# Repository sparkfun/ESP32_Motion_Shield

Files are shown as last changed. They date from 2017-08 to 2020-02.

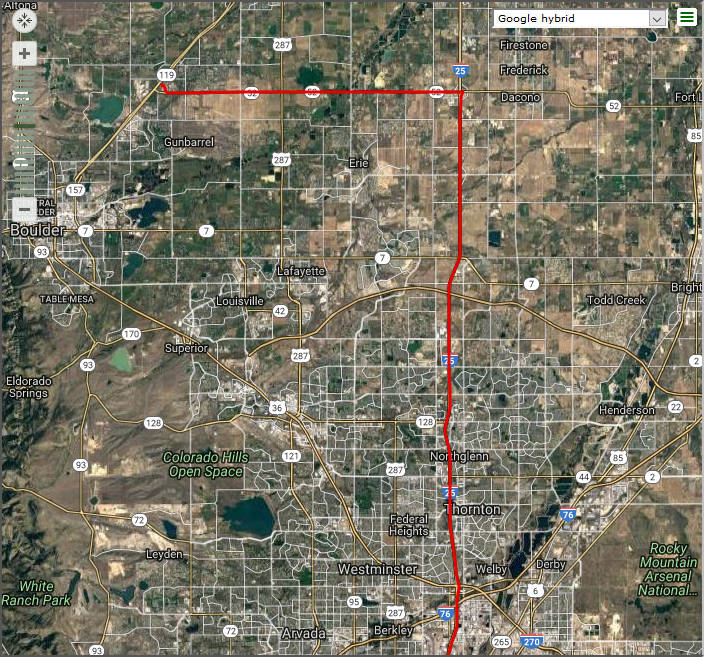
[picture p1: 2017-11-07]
Software/GPS_IMU_SD_Logger/extras/data_track.jpg

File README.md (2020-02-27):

SparkFun <PRODUCT NAME>
========================================

ESP32 Thing Motion Shield

The [ESP32 Thing Motion Shield](https://www.sparkfun.com/products/14430) is a versatile addition to our [ESP32 Thing](https://www.sparkfun.com/products/13907).  Small movements can be detected with the tried and true LSM9DS1 IMU, large movements and time can be detected with the addition of a GPS sensor.  There's a port for the [GP-20U7](https://www.sparkfun.com/products/13740) module, and breakout pins for any serial device.  Data can be easily logged by adding an microSD card to the slot.  There is also an additional user led on pin 13.

Repository Contents
-------------------

* **/Documentation** - Test plan and record.
* **/Hardware** - Eagle design files (.brd, .sch)
* **/Production** - Production panel files (.brd)
* **/Software** - Example programs for the ESP32 that can support functions of the Motion Shield.  These are used in the hookup guide.

Documentation
--------------
* **[Motion Shield Hookup Guide](https://learn.sparkfun.com/tutorials/esp32-thing-motion-shield-hookup-guide)** - Basic hookup guide for the ESP32 Motion Shield.
* **[ESP32 Hookup Guide](https://learn.sparkfun.com/tutorials/esp32-thing-hookup-guide)** - Basic hookup guide for the ESP32 Thing.

Product Versions
----------------
* [DEV-14430](https://www.sparkfun.com/products/14430) - ESP32 Motion Shield

Version History
---------------
* [V_1.0.0a](https://github.com/sparkfun/ESP32_Motion_Shield/releases/tag/v1.0.0a) - Software Update.
* [V_1.0.0](https://github.com/sparkfun/ESP32_Motion_Shield/tree/V_1.0.0) - Product release.

License Information
-------------------

This product is _**open source**_! 

Please review the LICENSE.md file for license information. 

If you have any questions or concerns on licensing, please contact techsupport@sparkfun.com.

Distributed as-is; no warranty is given.

- Your friends at SparkFun.

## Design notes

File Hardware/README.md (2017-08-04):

SparkFun <PRODUCT NAME> Design Files
=====================================

The .sch and .brd files hare are Eagle CAD schematic and PCB design files from SparkFun Electronics.
A freeware version of Eagle can be found [here](http://www.cadsoftusa.com/download-eagle/freeware/).

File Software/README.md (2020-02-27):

SparkFun ESP32 Motion Shield Software
=================================

Example software for use with SparkFun ESP32 Motion Shield.

LSM9DS1 and BME280 libraries need to be installed to work.

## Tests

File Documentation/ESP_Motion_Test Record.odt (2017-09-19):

# Functional Test Record

## SD card SPI bus and signal integrity

Configure an SD card to operate at fastest speed possible.

Procedure:

1. Perform 1M R/W test,
  1. Measure and record bus speed: __________
  2. Capture and record transaction beginning end such that timing can be seen, record two captures here

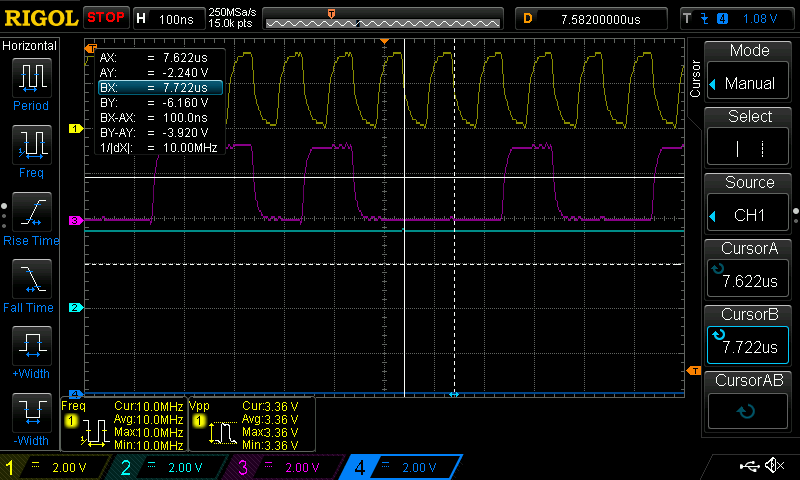
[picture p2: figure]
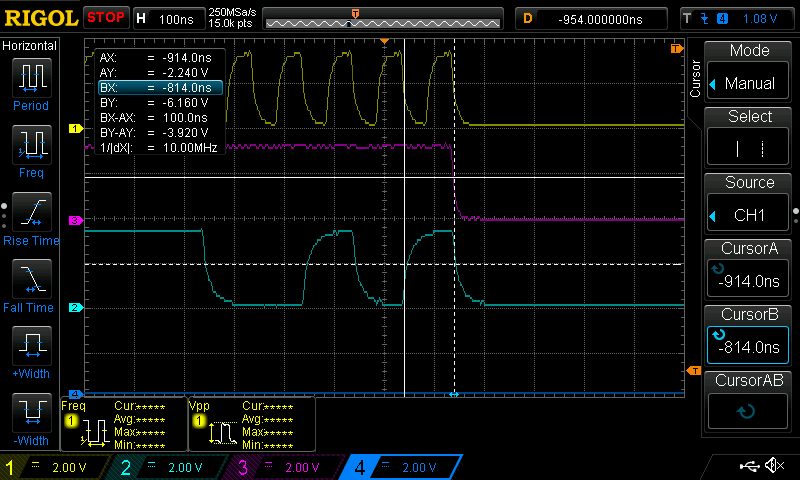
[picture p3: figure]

  1. Load the bus with another device
  2. Capture and record transaction beginning end such that timing can be seen, record two captures here

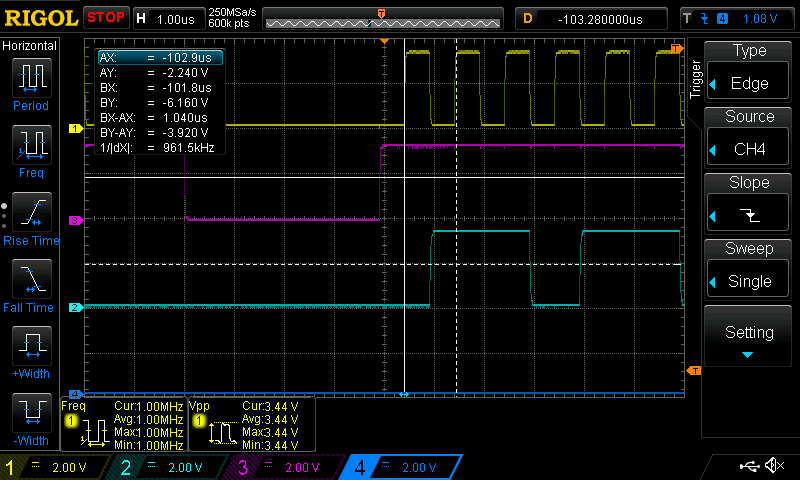
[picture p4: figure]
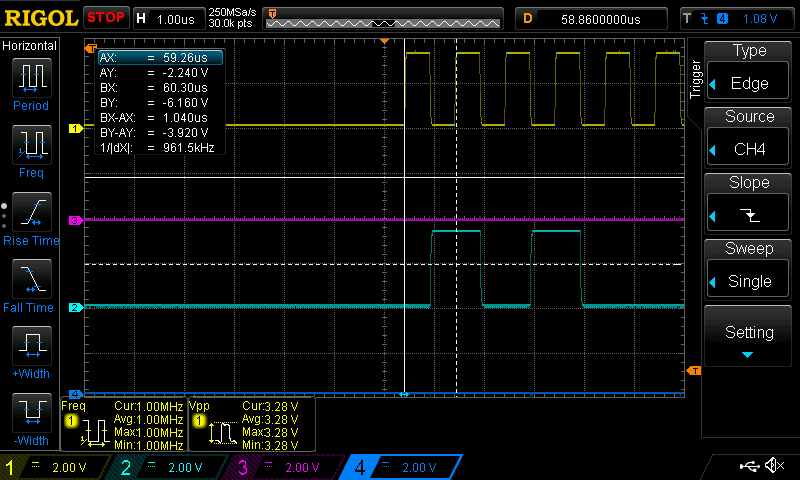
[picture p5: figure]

Criteria:

1. Does the SD car work alone, and with multiple devices? YES, Same bus speed limitation (probably max 1MHz)
2. Does the other device also work? YES
3. Do signals have sufficient setup and hold times? YES
4. Are signals monotonic? YES

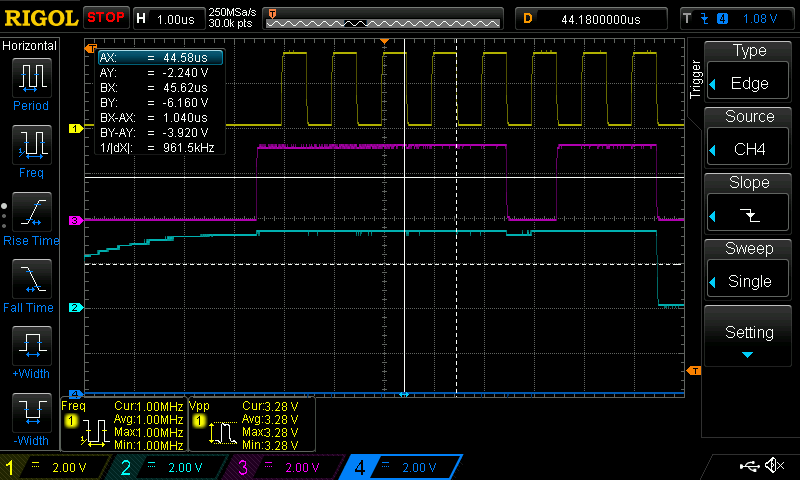
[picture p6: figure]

5. Are signals monotonic? YES/NO

## Check SD card CD function

Configure for SD card detection

Procedure:

1. With no card inserted, measure voltage on detect pin_____
2. With card inserted, measure voltage on detect pin_____
3. Recored pin configuration necessary here:

Criteria:

1. Do voltages fall outside ESP32 IO levels? NO – CD incorrectly wired, fixing in next rev

## IMU

Configure the gyro and accelerometer for use and measure bus conditions. Make a program that continuously reads all 9 axes.

Peform the following during read loop:

Procedure:

1. Measure and record bus speed: 100KHz
2. Capture and record transaction beginning end such that timing can be seen, record two captures here

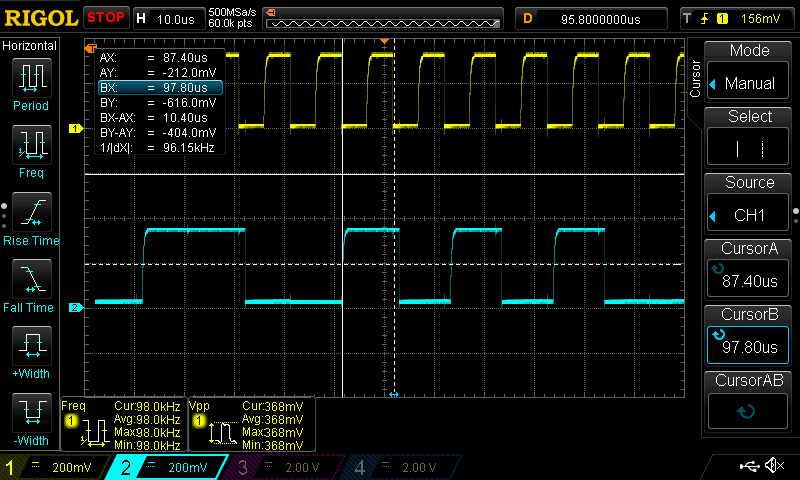
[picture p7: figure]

3. Load the bus with another device
4. Capture and record transaction beginning end such that timing can be seen, record two captures here

Criteria:

1. Does the other device also work? YES
2. Do signals have sufficient setup and hold times? YES
3. Are signals monotonic? YES

## Test IMU power features

Power switch has been scrapped

## Test the GPS port

Check that the serial pass-through is working fine

Procedure:

1. Loop-back the serial port
2. Run a program to return usb serial commands through the port
3. Capture a bit-variable character up to 115200 baud, measuring on the loopback
4. Measure the symbol rate for 9600, 57600, and 115200
  1. 9600: 9709, coming from cheap GPS, 9652 from loopback
  2. 57600: 57800 from loopback
  3. 115200: 115200 from loopback

Criteria:

1. Do the symbols have good integrity up to 115200? YES
2. Is the symbol rate correct? YES

## Test GPS module functionality

Expose GPS modules to the sky and check features

Procedure:

1. Attach 3 pin module.
2. Power device and wait for lock, record: _____
3. Record sample output:
4. Attach 4 pin module to holes
5. Power device and wait for lock, record: _____
6. Record sample output:

Criteria:

1. Does the cheap module work well? YES
2. Does the expensive module work well? SKIPPED
3. Is one module better than the other? YES/NO

## Test board power rails

Check that nothing is behaving stragely

For these tests, all functions should be running at greatest load

Procedure:

1. Measure ripple on power supply lines of shield: 7.6 mV p-p
2. Attach current probe to isolate 3.3V rail
3. Measure full load power draw: _____
4. Switch board on and off
5. Measure 3.3V rail rise time: 70uS

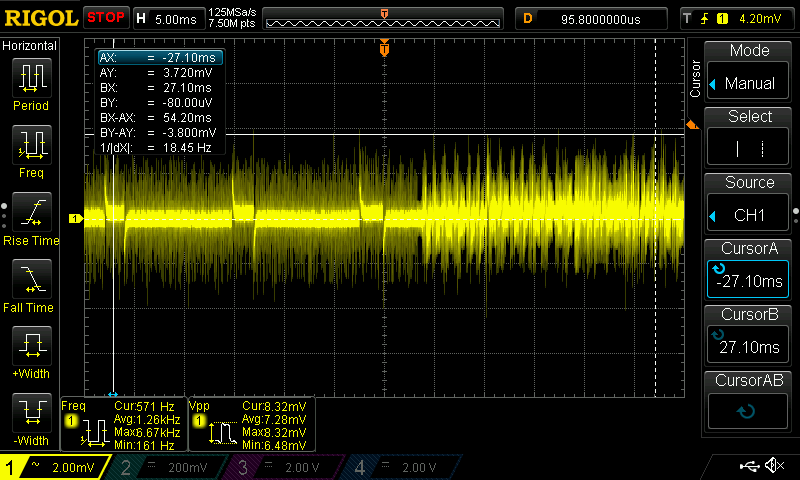
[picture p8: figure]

Criteria:

1. Is the current draw acceptable for battery use? SKIPPED
2. Is the rise time ok, > 10uS for IMU? YES
3. Is the ripple acceptable? YES

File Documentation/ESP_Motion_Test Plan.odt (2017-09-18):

# Functional Test Plan

## Features to verify

- SD card
  - Compatibility with other devices
  - Does CD work?
  - Signal integrity
- IMU
  - Gyro config and data
  - Accel config and data
  - Are additional pins needed?
  - Does power reset function? (can it be cold reboot?)
  - Signal integrity
- GPS
  - Does recommended GPS do its job?
  - Does hand-wired GPS also work?
  - Signal integrity
- Generic
  - What is the current consumption?
  - Are rise times OK?
  - Noise on power and ground?

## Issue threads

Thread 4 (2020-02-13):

Sensor fusion

romatou18, 2020-02-13:
hi I just had a quick look at the calcAttidude() function, if im correct it does not use any advanced, and now mainstream sensor fusion algorithm such as the Madgwick, or Mahony quarternion method ?

Do you plan on providing an algo for this board, this sensor ? The project has been out since 2017 it is kind of expected to have a decent IMU fusion integrated in the provided software perhaps.

Could you let us know ?

REgards

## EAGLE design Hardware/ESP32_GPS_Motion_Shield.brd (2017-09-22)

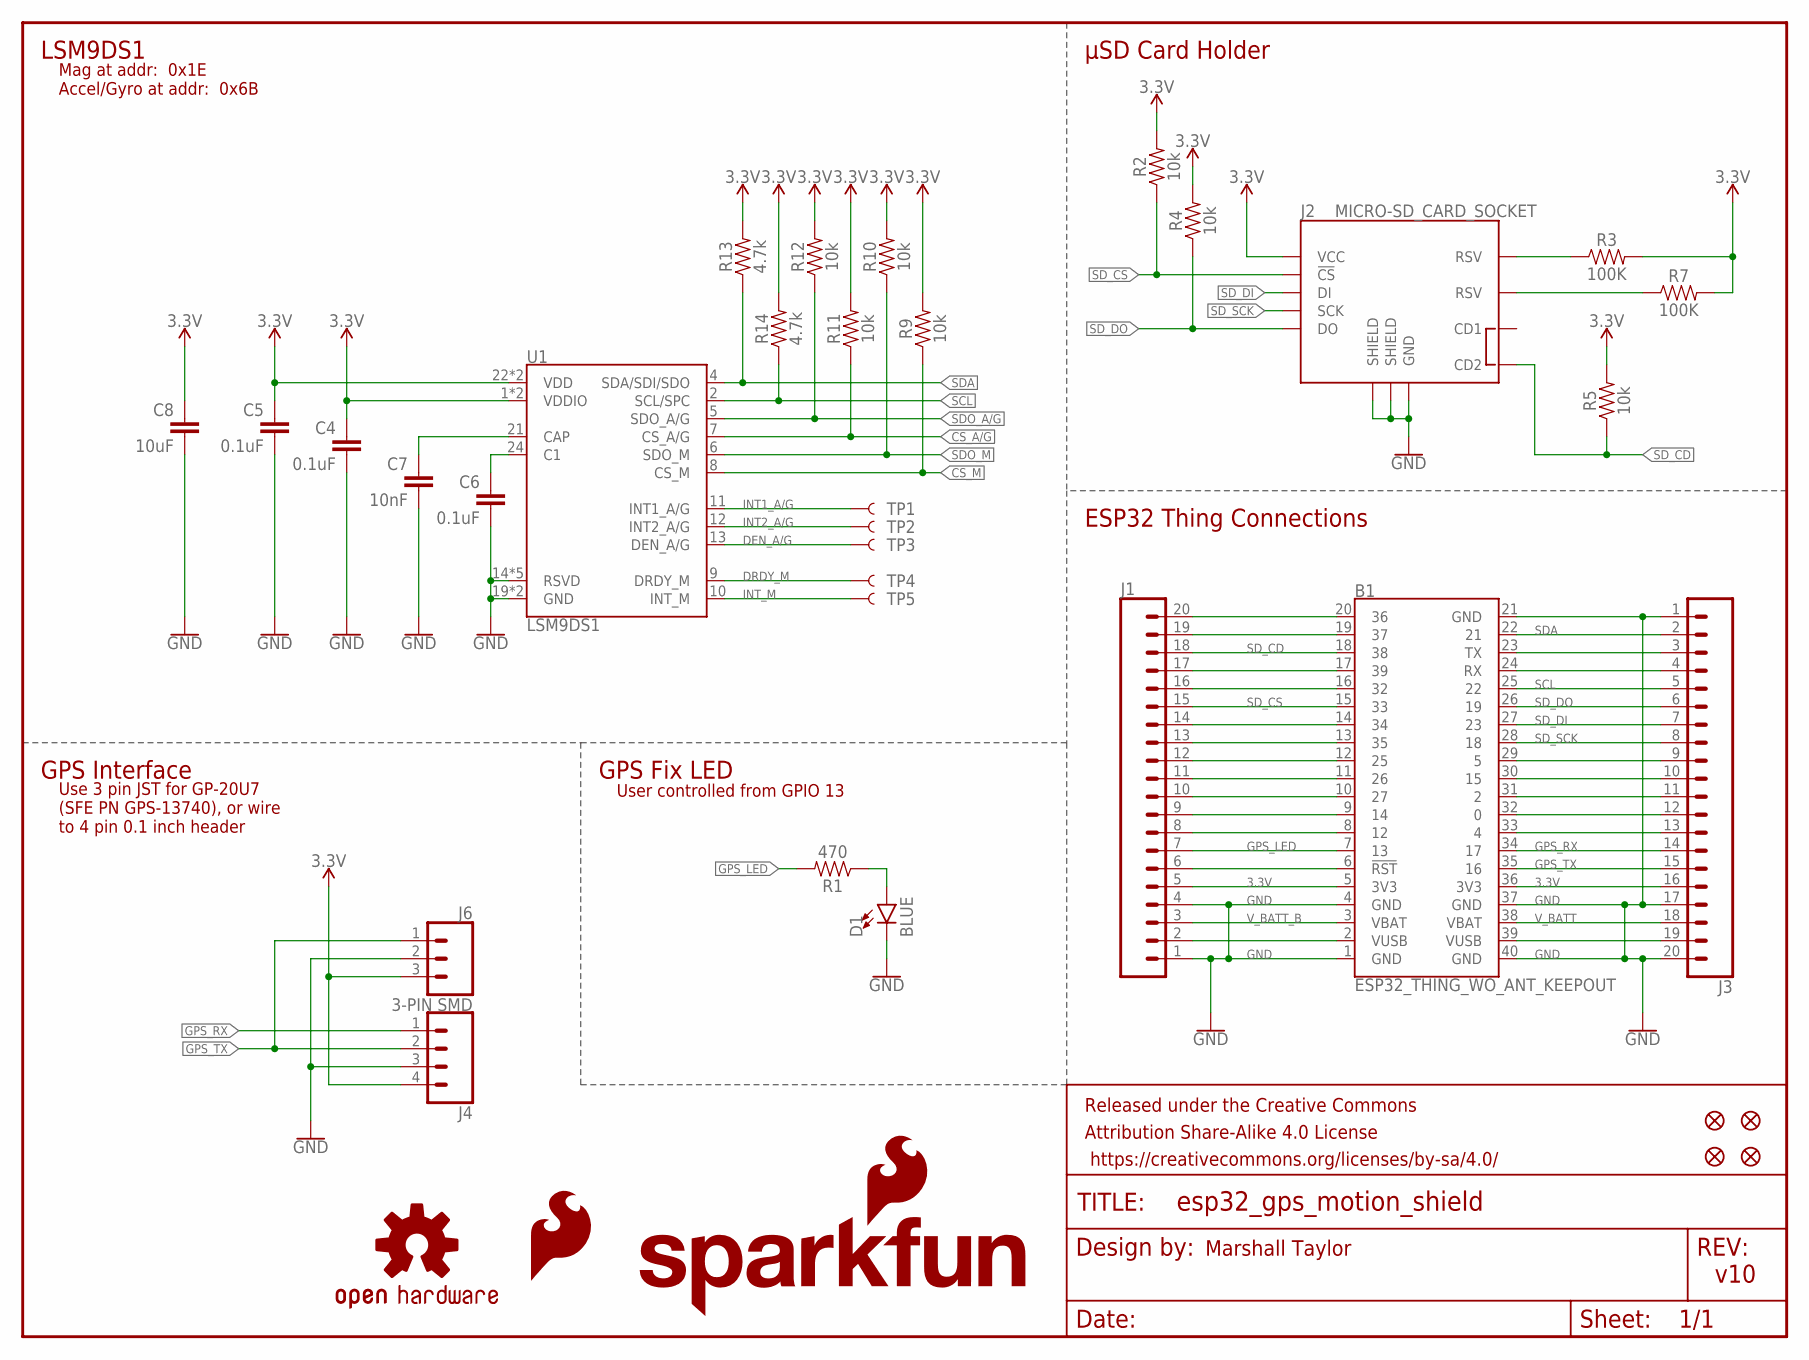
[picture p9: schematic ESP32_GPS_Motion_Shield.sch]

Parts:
B1: ESP32_THING_WO_ANT_KEEPOUT; ESP32_THING_NO_ANT
C4, C5, C6: 0.1uF; 0402
C7: 10nF; 0603
C8: 10uF; 0603
D1: BLUE; LED-0603
FD1, FD2, FD3, FD4: FIDUCIALUFIDUCIAL; FIDUCIAL-MICRO
FRAME1: FRAME-LETTER; CREATIVE_COMMONS
J1, J3: CONN_20NOSILK; 1X20_NOSILK
J2: MICRO-SD_CARD_SOCKET; MICRO-SD-SOCKET
J4: CONN_04; 1X04
J6: 3-PIN SMD; JST-3-SMD
LOGO1: OSHW-LOGOS; OSHW-LOGO-S
LOGO2: SFE_LOGO_NAME_FLAME.2_INCH; SFE_LOGO_NAME_FLAME_.2
LOGO3: SFE_LOGO_FLAME.1_INCH; SFE_LOGO_FLAME_.1
R1: 470; 0603
R2, R4, R5, R9, R10, R11, R12: 10k; 0603
R3, R7: 100K; 0402
R13, R14: 4.7k; 0603
TP1, TP2, TP3, TP4, TP5: TEST-POINT3; PAD.03X.03
U1: LSM9DS1; LGA-24-3.5X3

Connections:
3.3V: B1.5 (3V3), B1.36 (3V3), C4.1, C5.1, C8.1, J1.5, J2.VCC, J3.16, J4.4, J6.3 (1), R2.2, R3.2, R4.2, R5.2, R7.2, R9.2, R10.2, R11.2, R12.2, R13.2, R14.2, U1.1 (VDDIO), U1.3 (VDDIO), U1.22 (VDD), U1.23 (VDD)
C1: C6.1, U1.24 (C1)
CAP: C7.1, U1.21 (CAP)
CS_A/G: R11.1, U1.7 (CS_A/G)
CS_M: R9.1, U1.8 (CS_M)
DEN_A/G: TP3.P$1, U1.13 (DEN_A/G)
DRDY_M: TP4.P$1, U1.9 (DRDY_M)
GND: B1.1 (GND), B1.4 (GND), B1.21 (GND), B1.37 (GND), B1.40 (GND), C4.2, C5.2, C6.2, C7.2, C8.2, D1.C, J1.1, J1.4, J2.GND, J2.GND1 (SHIELD), J2.GND3 (SHIELD), J3.1, J3.17, J3.20, J4.3, J6.2, U1.14 (RSVD), U1.15 (RSVD), U1.16 (RSVD), U1.17 (RSVD), U1.18 (RSVD), U1.19 (GND), U1.20 (GND)
GPS_LED: B1.7 (13), J1.7, R1.2
GPS_RX: B1.34 (17), J3.14, J4.1
GPS_TX: B1.35 (16), J3.15, J4.2, J6.1 (3)
INT1_A/G: TP1.P$1, U1.11 (INT1_A/G)
INT2_A/G: TP2.P$1, U1.12 (INT2_A/G)
INT_M: TP5.P$1, U1.10 (INT_M)
unnamed: D1.A, R1.1
unnamed: B1.30 (15), J3.10
unnamed: B1.17 (39), J1.17
unnamed: B1.16 (32), J1.16
unnamed: B1.19 (37), J1.19
unnamed: B1.10 (27), J1.10
unnamed: B1.14 (34), J1.14
unnamed: J2.RSV1 (RSV), R3.1
unnamed: J2.RSV2 (RSV), R7.1
unnamed: B1.6 (!RST!), J1.6
unnamed: B1.8 (12), J1.8
unnamed: B1.9 (14), J1.9
unnamed: B1.11 (26), J1.11
unnamed: B1.12 (25), J1.12
unnamed: B1.13 (35), J1.13
unnamed: B1.20 (36), J1.20
unnamed: B1.23 (TX), J3.3
unnamed: B1.24 (RX), J3.4
unnamed: B1.29 (5), J3.9
unnamed: B1.31 (2), J3.11
unnamed: B1.32 (0), J3.12
unnamed: B1.33 (4), J3.13
SCL: B1.25 (22), J3.5, R14.1, U1.2 (SCL/SPC)
SDA: B1.22 (21), J3.2, R13.1, U1.4 (SDA/SDI/SDO)
SDO_A/G: R12.1, U1.5 (SDO_A/G)
SDO_M: R10.1, U1.6 (SDO_M)
SD_CD: B1.18 (38), J1.18, J2.CD2, R5.1
SD_CS: B1.15 (33), J1.15, J2.CS (!CS), R2.1
SD_DI: B1.27 (23), J2.DI, J3.7
SD_DO: B1.26 (19), J2.DO, J3.6, R4.1
SD_SCK: B1.28 (18), J2.SCLK (SCK), J3.8
VUSB: B1.39 (VUSB), J3.19
VUSB_B: B1.2 (VUSB), J1.2
V_BATT: B1.38 (VBAT), J3.18
V_BATT_B: B1.3 (VBAT), J1.3

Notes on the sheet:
GPS Interface
μSD Card Holder
GPS Fix LED
v10
Marshall Taylor
LSM9DS1
ESP32 Thing Connections
User controlled from GPIO 13
Use 3 pin JST for GP-20U7 (SFE PN GPS-13740), or wire to 4 pin 0.1 inch header
Mag at addr: 0x1E Accel/Gyro at addr: 0x6B

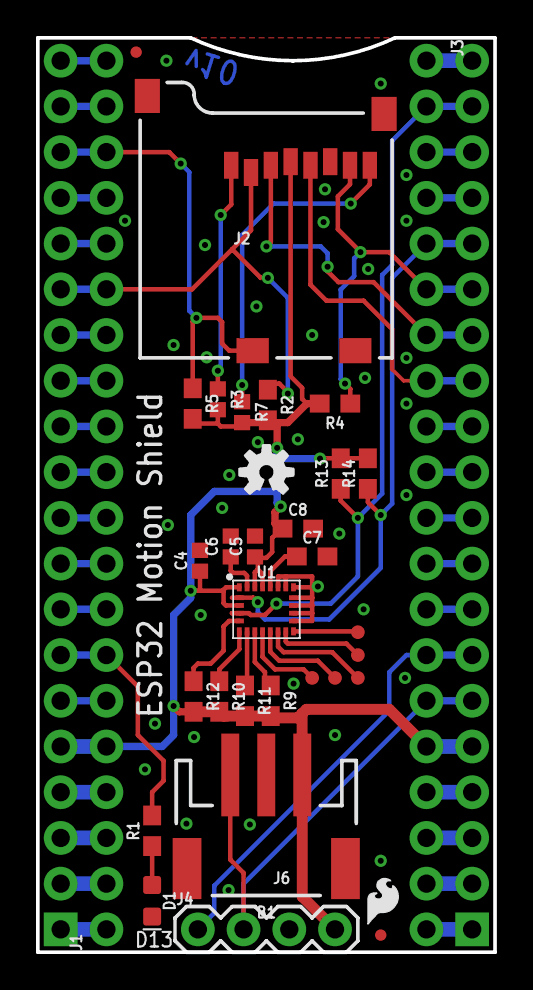
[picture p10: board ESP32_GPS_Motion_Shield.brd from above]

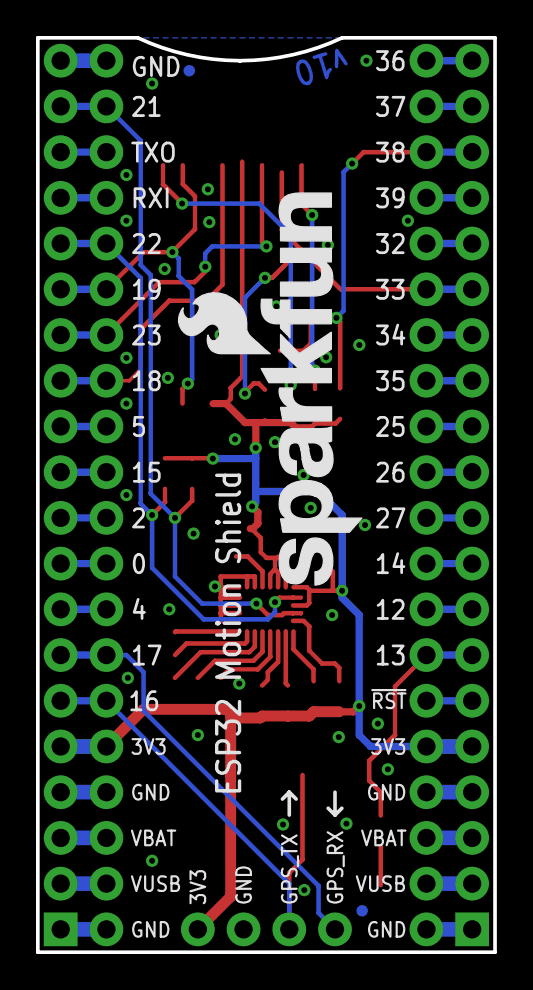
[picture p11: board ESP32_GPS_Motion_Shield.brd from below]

Board: 2 copper layers, 25.4 x 50.8 mm, 38 parts (3 on the bottom side), 49 nets.

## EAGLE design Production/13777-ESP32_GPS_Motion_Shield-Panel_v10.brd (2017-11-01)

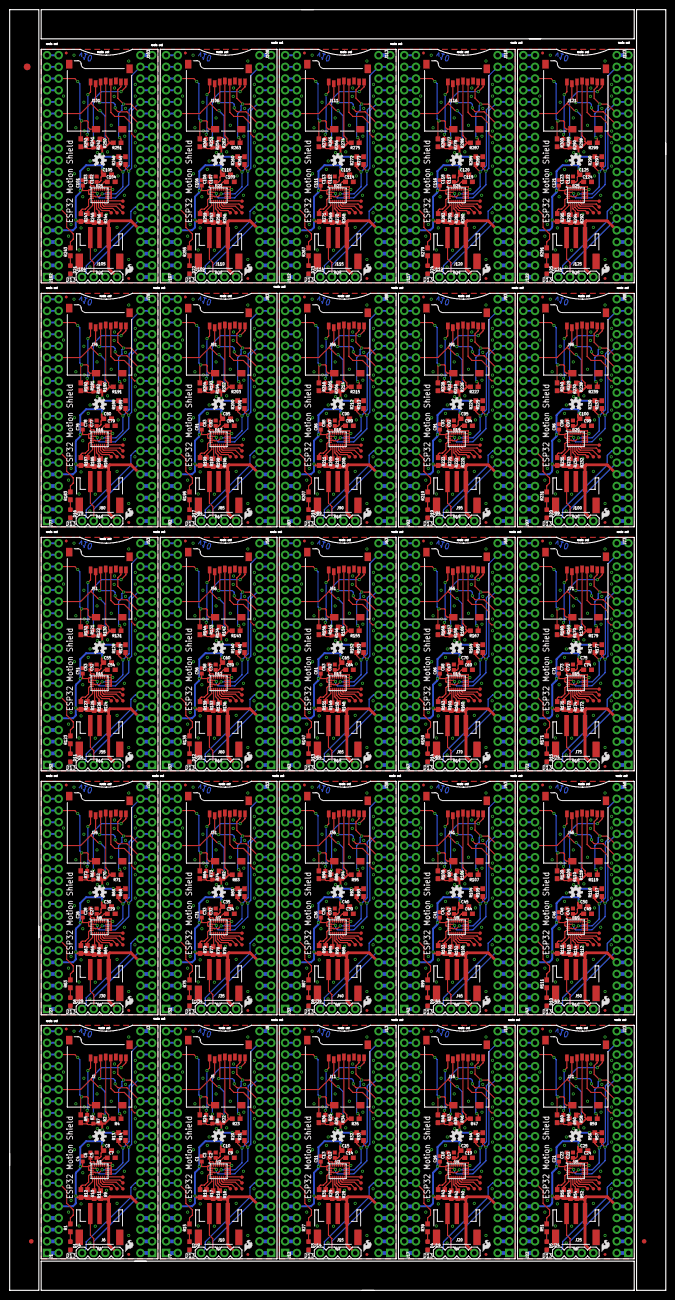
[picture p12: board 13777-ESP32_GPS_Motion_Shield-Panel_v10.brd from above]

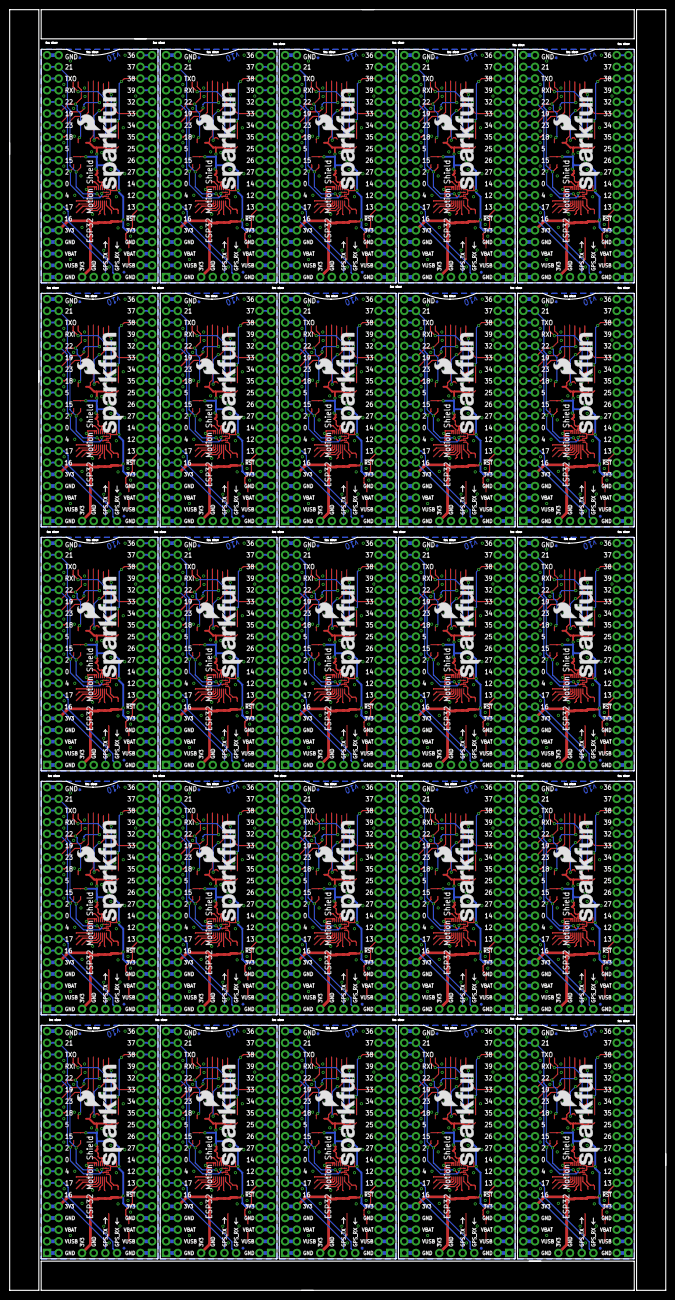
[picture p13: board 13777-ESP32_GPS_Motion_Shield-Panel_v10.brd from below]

Board: 2 copper layers, 142.7 x 278.6 mm, 928 parts (75 on the bottom side), 1225 nets.

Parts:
B1, B2, B3, B4, B5, B6, B7, B8, B9, B10, B11, B12, B13, B14, B15, B16, B17, B18, B19, B20, B21, B22, B23, B24, B25: ESP32_THING_WO_ANT_KEEPOUT; ESP32_THING_NO_ANT
C1, C2, C3, C4, C5, C6, C11, C12, C13, C16, C17, C18, C21, C22, C23, C26, C27, C28, C31, C32, C33, C36, C37, C38, C41, C42, C43, C46, C47, C48, C51, C52, C53, C56, C57, C58, C61, C62, C63, C66, C67, C68, C71, C72, C73, C76, C77, C78, C81, C82, C83, C86, C87, C88, C91, C92, C93, C96, C97, C98, C101, C102, C103, C106, C107, C108, C111, C112, C113, C116, C117, C118, C121, C122, C123: 0.1uF; 0402
C7, C9, C14, C19, C24, C29, C34, C39, C44, C49, C54, C59, C64, C69, C74, C79, C84, C89, C94, C99, C104, C109, C114, C119, C124: 10nF; 0603
C8, C10, C15, C20, C25, C30, C35, C40, C45, C50, C55, C60, C65, C70, C75, C80, C85, C90, C95, C100, C105, C110, C115, C120, C125: 10uF; 0603
D1, D2, D3, D4, D5, D6, D7, D8, D9, D10, D11, D12, D13, D14, D15, D16, D17, D18, D19, D20, D21, D22, D23, D24, D25: BLUE; LED-0603
E$1, E$2: FIDUCIAL-1X2
E$3: FIDUCIAL-1.5X3
FD1, FD2, FD3, FD4, FD5, FD6, FD7, FD8, FD9, FD10, FD11, FD12, FD13, FD14, FD15, FD16, FD17, FD18, FD19, FD20, FD21, FD22, FD23, FD24, FD25, FD26, FD27, FD28, FD29, FD30, FD31, FD32, FD33, FD34, FD35, FD36, FD37, FD38, FD39, FD40, FD41, FD42, FD43, FD44, FD45, FD46, FD47, FD48, FD49, FD50, FD51, FD52, FD53, FD54, FD55, FD56, FD57, FD58, FD59, FD60, FD61, FD62, FD63, FD64, FD65, FD66, FD67, FD68, FD69, FD70, FD71, FD72, FD73, FD74, FD75, FD76, FD77, FD78, FD79, FD80, FD81, FD82, FD83, FD84, FD85, FD86, FD87, FD88, FD89, FD90, FD91, FD92, FD93, FD94, FD95, FD96, FD97, FD98, FD99, FD100: FIDUCIALUFIDUCIAL; FIDUCIAL-MICRO
J1, J3, J7, J8, J12, J13, J17, J18, J22, J23, J27, J28, J32, J33, J37, J38, J42, J43, J47, J48, J52, J53, J57, J58, J62, J63, J67, J68, J72, J73, J77, J78, J82, J83, J87, J88, J92, J93, J97, J98, J102, J103, J107, J108, J112, J113, J117, J118, J122, J123: 1X20_NOSILK
J2, J5, J11, J16, J21, J26, J31, J36, J41, J46, J51, J56, J61, J66, J71, J76, J81, J86, J91, J96, J101, J106, J111, J116, J121: MICRO-SD_CARD_SOCKET; MICRO-SD-SOCKET
J4, J9, J14, J19, J24, J29, J34, J39, J44, J49, J54, J59, J64, J69, J74, J79, J84, J89, J94, J99, J104, J109, J114, J119, J124: 1X04
J6, J10, J15, J20, J25, J30, J35, J40, J45, J50, J55, J60, J65, J70, J75, J80, J85, J90, J95, J100, J105, J110, J115, J120, J125: 3-PIN SMD; JST-3-SMD
LOGO1, LOGO4, LOGO7, LOGO10, LOGO13, LOGO16, LOGO19, LOGO22, LOGO25, LOGO28, LOGO31, LOGO34, LOGO37, LOGO40, LOGO43, LOGO46, LOGO49, LOGO52, LOGO55, LOGO58, LOGO61, LOGO64, LOGO67, LOGO70, LOGO73: OSHW-LOGOS; OSHW-LOGO-S
LOGO2, LOGO6, LOGO9, LOGO12, LOGO15, LOGO18, LOGO21, LOGO24, LOGO27, LOGO30, LOGO33, LOGO36, LOGO39, LOGO42, LOGO45, LOGO48, LOGO51, LOGO54, LOGO57, LOGO60, LOGO63, LOGO66, LOGO69, LOGO72, LOGO75: SFE_LOGO_NAME_FLAME.2_INCH; SFE_LOGO_NAME_FLAME_.2
LOGO3, LOGO5, LOGO8, LOGO11, LOGO14, LOGO17, LOGO20, LOGO23, LOGO26, LOGO29, LOGO32, LOGO35, LOGO38, LOGO41, LOGO44, LOGO47, LOGO50, LOGO53, LOGO56, LOGO59, LOGO62, LOGO65, LOGO68, LOGO71, LOGO74: SFE_LOGO_FLAME.1_INCH; SFE_LOGO_FLAME_.1
R1, R15, R27, R39, R51, R63, R75, R87, R99, R111, R123, R135, R147, R159, R171, R183, R195, R207, R219, R231, R243, R255, R267, R279, R291: 470; 0603
R2, R4, R5, R9, R10, R11, R12, R16, R17, R18, R19, R22, R23, R24, R28, R29, R30, R31, R34, R35, R36, R40, R41, R42, R43, R46, R47, R48, R52, R53, R54, R55, R58, R59, R60, R64, R65, R66, R67, R70, R71, R72, R76, R77, R78, R79, R82, R83, R84, R88, R89, R90, R91, R94, R95, R96, R100, R101, R102, R103, R106, R107, R108, R112, R113, R114, R115, R118, R119, R120, R124, R125, R126, R127, R130, R131, R132, R136, R137, R138, R139, R142, R143, R144, R148, R149, R150, R151, R154, R155, R156, R160, R161, R162, R163, R166, R167, R168, R172, R173, R174, R175, R178, R179, R180, R184, R185, R186, R187, R190, R191, R192, R196, R197, R198, R199, R202, R203, R204, R208, R209, R210, R211, R214, R215, R216, R220, R221, R222, R223, R226, R227, R228, R232, R233, R234, R235, R238, R239, R240, R244, R245, R246, R247, R250, R251, R252, R256, R257, R258, R259, R262, R263, R264, R268, R269, R270, R271, R274, R275, R276, R280, R281, R282, R283, R286, R287, R288, R292, R293, R294, R295, R298, R299, R300: 10k; 0603
R3, R6, R7, R8, R25, R26, R37, R38, R49, R50, R61, R62, R73, R74, R85, R86, R97, R98, R109, R110, R121, R122, R133, R134, R145, R146, R157, R158, R169, R170, R181, R182, R193, R194, R205, R206, R217, R218, R229, R230, R241, R242, R253, R254, R265, R266, R277, R278, R289, R290: 100K; 0402
R13, R14, R20, R21, R32, R33, R44, R45, R56, R57, R68, R69, R80, R81, R92, R93, R104, R105, R116, R117, R128, R129, R140, R141, R152, R153, R164, R165, R176, R177, R188, R189, R200, R201, R212, R213, R224, R225, R236, R237, R248, R249, R260, R261, R272, R273, R284, R285, R296, R297: 4.7k; 0603
TP1, TP2, TP3, TP4, TP5, TP6, TP7, TP8, TP9, TP10, TP11, TP12, TP13, TP14, TP15, TP16, TP17, TP18, TP19, TP20, TP21, TP22, TP23, TP24, TP25, TP26, TP27, TP28, TP29, TP30, TP31, TP32, TP33, TP34, TP35, TP36, TP37, TP38, TP39, TP40, TP41, TP42, TP43, TP44, TP45, TP46, TP47, TP48, TP49, TP50, TP51, TP52, TP53, TP54, TP55, TP56, TP57, TP58, TP59, TP60, TP61, TP62, TP63, TP64, TP65, TP66, TP67, TP68, TP69, TP70, TP71, TP72, TP73, TP74, TP75, TP76, TP77, TP78, TP79, TP80, TP81, TP82, TP83, TP84, TP85, TP86, TP87, TP88, TP89, TP90, TP91, TP92, TP93, TP94, TP95, TP96, TP97, TP98, TP99, TP100, TP101, TP102, TP103, TP104, TP105, TP106, TP107, TP108, TP109, TP110, TP111, TP112, TP113, TP114, TP115, TP116, TP117, TP118, TP119, TP120, TP121, TP122, TP123, TP124, TP125: TEST-POINT3; PAD.03X.03
U1, U2, U3, U4, U5, U6, U7, U8, U9, U10, U11, U12, U13, U14, U15, U16, U17, U18, U19, U20, U21, U22, U23, U24, U25: LSM9DS1; LGA-24-3.5X3

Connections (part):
3.3V: B1.5, B1.36, C4.1, C5.1, C8.1, J1.5, J2.VCC, J3.16, J4.4, J6.3, R2.2, R3.2, R4.2, R5.2, R7.2, R9.2, R10.2, R11.2, R12.2, R13.2, R14.2, U1.1, U1.3, U1.22, U1.23
3.3V1: B2.5, B2.36, C1.1, C2.1, C10.1, J5.VCC, J7.5, J8.16, J9.4, J10.3, R6.2, R8.2, R16.2, R17.2, R18.2, R19.2, R20.2, R21.2, R22.2, R23.2, R24.2, U2.1, U2.3, U2.22, U2.23
3.3V2: B3.5, B3.36, C11.1, C12.1, C15.1, J11.VCC, J12.5, J13.16, J14.4, J15.3, R25.2, R26.2, R28.2, R29.2, R30.2, R31.2, R32.2, R33.2, R34.2, R35.2, R36.2, U3.1, U3.3, U3.22, U3.23
3.3V3: B4.5, B4.36, C16.1, C17.1, C20.1, J16.VCC, J17.5, J18.16, J19.4, J20.3, R37.2, R38.2, R40.2, R41.2, R42.2, R43.2, R44.2, R45.2, R46.2, R47.2, R48.2, U4.1, U4.3, U4.22, U4.23
3.3V4: B5.5, B5.36, C21.1, C22.1, C25.1, J21.VCC, J22.5, J23.16, J24.4, J25.3, R49.2, R50.2, R52.2, R53.2, R54.2, R55.2, R56.2, R57.2, R58.2, R59.2, R60.2, U5.1, U5.3, U5.22, U5.23
3.3V5: B6.5, B6.36, C26.1, C27.1, C30.1, J26.VCC, J27.5, J28.16, J29.4, J30.3, R61.2, R62.2, R64.2, R65.2, R66.2, R67.2, R68.2, R69.2, R70.2, R71.2, R72.2, U6.1, U6.3, U6.22, U6.23
3.3V6: B7.5, B7.36, C31.1, C32.1, C35.1, J31.VCC, J32.5, J33.16, J34.4, J35.3, R73.2, R74.2, R76.2, R77.2, R78.2, R79.2, R80.2, R81.2, R82.2, R83.2, R84.2, U7.1, U7.3, U7.22, U7.23
3.3V7: B8.5, B8.36, C36.1, C37.1, C40.1, J36.VCC, J37.5, J38.16, J39.4, J40.3, R85.2, R86.2, R88.2, R89.2, R90.2, R91.2, R92.2, R93.2, R94.2, R95.2, R96.2, U8.1, U8.3, U8.22, U8.23
3.3V8: B9.5, B9.36, C41.1, C42.1, C45.1, J41.VCC, J42.5, J43.16, J44.4, J45.3, R97.2, R98.2, R100.2, R101.2, R102.2, R103.2, R104.2, R105.2, R106.2, R107.2, R108.2, U9.1, U9.3, U9.22, U9.23
3.3V9: B10.5, B10.36, C46.1, C47.1, C50.1, J46.VCC, J47.5, J48.16, J49.4, J50.3, R109.2, R110.2, R112.2, R113.2, R114.2, R115.2, R116.2, R117.2, R118.2, R119.2, R120.2, U10.1, U10.3, U10.22, U10.23
3.3V10: B11.5, B11.36, C51.1, C52.1, C55.1, J51.VCC, J52.5, J53.16, J54.4, J55.3, R121.2, R122.2, R124.2, R125.2, R126.2, R127.2, R128.2, R129.2, R130.2, R131.2, R132.2, U11.1, U11.3, U11.22, U11.23
3.3V11: B12.5, B12.36, C56.1, C57.1, C60.1, J56.VCC, J57.5, J58.16, J59.4, J60.3, R133.2, R134.2, R136.2, R137.2, R138.2, R139.2, R140.2, R141.2, R142.2, R143.2, R144.2, U12.1, U12.3, U12.22, U12.23
3.3V12: B13.5, B13.36, C61.1, C62.1, C65.1, J61.VCC, J62.5, J63.16, J64.4, J65.3, R145.2, R146.2, R148.2, R149.2, R150.2, R151.2, R152.2, R153.2, R154.2, R155.2, R156.2, U13.1, U13.3, U13.22, U13.23
3.3V13: B14.5, B14.36, C66.1, C67.1, C70.1, J66.VCC, J67.5, J68.16, J69.4, J70.3, R157.2, R158.2, R160.2, R161.2, R162.2, R163.2, R164.2, R165.2, R166.2, R167.2, R168.2, U14.1, U14.3, U14.22, U14.23
3.3V14: B15.5, B15.36, C71.1, C72.1, C75.1, J71.VCC, J72.5, J73.16, J74.4, J75.3, R169.2, R170.2, R172.2, R173.2, R174.2, R175.2, R176.2, R177.2, R178.2, R179.2, R180.2, U15.1, U15.3, U15.22, U15.23
3.3V15: B16.5, B16.36, C76.1, C77.1, C80.1, J76.VCC, J77.5, J78.16, J79.4, J80.3, R181.2, R182.2, R184.2, R185.2, R186.2, R187.2, R188.2, R189.2, R190.2, R191.2, R192.2, U16.1, U16.3, U16.22, U16.23
3.3V16: B17.5, B17.36, C81.1, C82.1, C85.1, J81.VCC, J82.5, J83.16, J84.4, J85.3, R193.2, R194.2, R196.2, R197.2, R198.2, R199.2, R200.2, R201.2, R202.2, R203.2, R204.2, U17.1, U17.3, U17.22, U17.23
3.3V17: B18.5, B18.36, C86.1, C87.1, C90.1, J86.VCC, J87.5, J88.16, J89.4, J90.3, R205.2, R206.2, R208.2, R209.2, R210.2, R211.2, R212.2, R213.2, R214.2, R215.2, R216.2, U18.1, U18.3, U18.22, U18.23
3.3V18: B19.5, B19.36, C91.1, C92.1, C95.1, J91.VCC, J92.5, J93.16, J94.4, J95.3, R217.2, R218.2, R220.2, R221.2, R222.2, R223.2, R224.2, R225.2, R226.2, R227.2, R228.2, U19.1, U19.3, U19.22, U19.23
3.3V19: B20.5, B20.36, C96.1, C97.1, C100.1, J96.VCC, J97.5, J98.16, J99.4, J100.3, R229.2, R230.2, R232.2, R233.2, R234.2, R235.2, R236.2, R237.2, R238.2, R239.2, R240.2, U20.1, U20.3, U20.22, U20.23
3.3V20: B21.5, B21.36, C101.1, C102.1, C105.1, J101.VCC, J102.5, J103.16, J104.4, J105.3, R241.2, R242.2, R244.2, R245.2, R246.2, R247.2, R248.2, R249.2, R250.2, R251.2, R252.2, U21.1, U21.3, U21.22, U21.23
3.3V21: B22.5, B22.36, C106.1, C107.1, C110.1, J106.VCC, J107.5, J108.16, J109.4, J110.3, R253.2, R254.2, R256.2, R257.2, R258.2, R259.2, R260.2, R261.2, R262.2, R263.2, R264.2, U22.1, U22.3, U22.22, U22.23
3.3V22: B23.5, B23.36, C111.1, C112.1, C115.1, J111.VCC, J112.5, J113.16, J114.4, J115.3, R265.2, R266.2, R268.2, R269.2, R270.2, R271.2, R272.2, R273.2, R274.2, R275.2, R276.2, U23.1, U23.3, U23.22, U23.23
3.3V23: B24.5, B24.36, C116.1, C117.1, C120.1, J116.VCC, J117.5, J118.16, J119.4, J120.3, R277.2, R278.2, R280.2, R281.2, R282.2, R283.2, R284.2, R285.2, R286.2, R287.2, R288.2, U24.1, U24.3, U24.22, U24.23
3.3V24: B25.5, B25.36, C121.1, C122.1, C125.1, J121.VCC, J122.5, J123.16, J124.4, J125.3, R289.2, R290.2, R292.2, R293.2, R294.2, R295.2, R296.2, R297.2, R298.2, R299.2, R300.2, U25.1, U25.3, U25.22, U25.23
C1: C6.1, U1.24
C2: C3.1, U2.24
C3: C13.1, U3.24
C4: C18.1, U4.24
C5: C23.1, U5.24
C6: C28.1, U6.24
C7: C33.1, U7.24
C8: C38.1, U8.24
C9: C43.1, U9.24
C10: C48.1, U10.24
C11: C53.1, U11.24
C12: C58.1, U12.24
C13: C63.1, U13.24
C14: C68.1, U14.24
C15: C73.1, U15.24
C16: C78.1, U16.24
C17: C83.1, U17.24
C18: C88.1, U18.24
C19: C93.1, U19.24
C20: C98.1, U20.24
C21: C103.1, U21.24
C22: C108.1, U22.24
C23: C113.1, U23.24
C24: C118.1, U24.24
C25: C123.1, U25.24
CAP: C7.1, U1.21
CAP1: C9.1, U2.21
CAP2: C14.1, U3.21
CAP3: C19.1, U4.21
CAP4: C24.1, U5.21
CAP5: C29.1, U6.21
CAP6: C34.1, U7.21
CAP7: C39.1, U8.21
CAP8: C44.1, U9.21
CAP9: C49.1, U10.21
CAP10: C54.1, U11.21
CAP11: C59.1, U12.21
CAP12: C64.1, U13.21
CAP13: C69.1, U14.21
CAP14: C74.1, U15.21
CAP15: C79.1, U16.21
CAP16: C84.1, U17.21
CAP17: C89.1, U18.21
CAP18: C94.1, U19.21
CAP19: C99.1, U20.21
CAP20: C104.1, U21.21
CAP21: C109.1, U22.21
CAP22: C114.1, U23.21
CAP23: C119.1, U24.21
CAP24: C124.1, U25.21
CS_A/G: R11.1, U1.7
CS_A/G1: R18.1, U2.7
CS_A/G2: R30.1, U3.7
CS_A/G3: R42.1, U4.7
CS_A/G4: R54.1, U5.7
CS_A/G5: R66.1, U6.7
CS_A/G6: R78.1, U7.7
CS_A/G7: R90.1, U8.7
CS_A/G8: R102.1, U9.7
CS_A/G9: R114.1, U10.7
CS_A/G10: R126.1, U11.7
CS_A/G11: R138.1, U12.7
CS_A/G12: R150.1, U13.7
CS_A/G13: R162.1, U14.7
CS_A/G14: R174.1, U15.7
CS_A/G15: R186.1, U16.7
CS_A/G16: R198.1, U17.7
CS_A/G17: R210.1, U18.7
CS_A/G18: R222.1, U19.7
CS_A/G19: R234.1, U20.7
CS_A/G20: R246.1, U21.7
CS_A/G21: R258.1, U22.7
CS_A/G22: R270.1, U23.7
CS_A/G23: R282.1, U24.7
CS_A/G24: R294.1, U25.7
CS_M: R9.1, U1.8
CS_M1: R16.1, U2.8
CS_M2: R28.1, U3.8
CS_M3: R40.1, U4.8
CS_M4: R52.1, U5.8
CS_M5: R64.1, U6.8
CS_M6: R76.1, U7.8
CS_M7: R88.1, U8.8
CS_M8: R100.1, U9.8
CS_M9: R112.1, U10.8
CS_M10: R124.1, U11.8
CS_M11: R136.1, U12.8
CS_M12: R148.1, U13.8
CS_M13: R160.1, U14.8
CS_M14: R172.1, U15.8
CS_M15: R184.1, U16.8
CS_M16: R196.1, U17.8
CS_M17: R208.1, U18.8
CS_M18: R220.1, U19.8
CS_M19: R232.1, U20.8
CS_M20: R244.1, U21.8
CS_M21: R256.1, U22.8
CS_M22: R268.1, U23.8
CS_M23: R280.1, U24.8
CS_M24: R292.1, U25.8
DEN_A/G: TP3.P$1, U1.13
DEN_A/G1: TP8.P$1, U2.13
DEN_A/G2: TP13.P$1, U3.13
DEN_A/G3: TP18.P$1, U4.13
DEN_A/G4: TP23.P$1, U5.13
DEN_A/G5: TP28.P$1, U6.13
DEN_A/G6: TP33.P$1, U7.13
DEN_A/G7: TP38.P$1, U8.13
DEN_A/G8: TP43.P$1, U9.13
DEN_A/G9: TP48.P$1, U10.13
DEN_A/G10: TP53.P$1, U11.13
DEN_A/G11: TP58.P$1, U12.13
DEN_A/G12: TP63.P$1, U13.13
DEN_A/G13: TP68.P$1, U14.13
DEN_A/G14: TP73.P$1, U15.13
DEN_A/G15: TP78.P$1, U16.13
DEN_A/G16: TP83.P$1, U17.13
DEN_A/G17: TP88.P$1, U18.13
DEN_A/G18: TP93.P$1, U19.13
DEN_A/G19: TP98.P$1, U20.13
DEN_A/G20: TP103.P$1, U21.13
DEN_A/G21: TP108.P$1, U22.13
DEN_A/G22: TP113.P$1, U23.13
DEN_A/G23: TP118.P$1, U24.13
DEN_A/G24: TP123.P$1, U25.13
DRDY_M: TP4.P$1, U1.9
DRDY_M1: TP9.P$1, U2.9
DRDY_M2: TP14.P$1, U3.9
DRDY_M3: TP19.P$1, U4.9
DRDY_M4: TP24.P$1, U5.9
DRDY_M5: TP29.P$1, U6.9
DRDY_M6: TP34.P$1, U7.9
DRDY_M7: TP39.P$1, U8.9
DRDY_M8: TP44.P$1, U9.9
DRDY_M9: TP49.P$1, U10.9
DRDY_M10: TP54.P$1, U11.9
DRDY_M11: TP59.P$1, U12.9
DRDY_M12: TP64.P$1, U13.9
DRDY_M13: TP69.P$1, U14.9
DRDY_M14: TP74.P$1, U15.9
DRDY_M15: TP79.P$1, U16.9
DRDY_M16: TP84.P$1, U17.9
DRDY_M17: TP89.P$1, U18.9
DRDY_M18: TP94.P$1, U19.9
DRDY_M19: TP99.P$1, U20.9
DRDY_M20: TP104.P$1, U21.9
DRDY_M21: TP109.P$1, U22.9
DRDY_M22: TP114.P$1, U23.9
DRDY_M23: TP119.P$1, U24.9
DRDY_M24: TP124.P$1, U25.9
GND: B1.1, B1.4, B1.21, B1.37, B1.40, C4.2, C5.2, C6.2, C7.2, C8.2, D1.C, J1.1, J1.4, J2.GND, J2.GND1, J2.GND3, J3.1, J3.17, J3.20, J4.3, J6.2, U1.14, U1.15, U1.16, U1.17, U1.18, U1.19, U1.20
GND1: B2.1, B2.4, B2.21, B2.37, B2.40, C1.2, C2.2, C3.2, C9.2, C10.2, D2.C, J5.GND, J5.GND1, J5.GND3, J7.1, J7.4, J8.1, J8.17, J8.20, J9.3, J10.2, U2.14, U2.15, U2.16, U2.17, U2.18, U2.19, U2.20
GND2: B3.1, B3.4, B3.21, B3.37, B3.40, C11.2, C12.2, C13.2, C14.2, C15.2, D3.C, J11.GND, J11.GND1, J11.GND3, J12.1, J12.4, J13.1, J13.17, J13.20, J14.3, J15.2, U3.14, U3.15, U3.16, U3.17, U3.18, U3.19, U3.20
GND3: B4.1, B4.4, B4.21, B4.37, B4.40, C16.2, C17.2, C18.2, C19.2, C20.2, D4.C, J16.GND, J16.GND1, J16.GND3, J17.1, J17.4, J18.1, J18.17, J18.20, J19.3, J20.2, U4.14, U4.15, U4.16, U4.17, U4.18, U4.19, U4.20
GND4: B5.1, B5.4, B5.21, B5.37, B5.40, C21.2, C22.2, C23.2, C24.2, C25.2, D5.C, J21.GND, J21.GND1, J21.GND3, J22.1, J22.4, J23.1, J23.17, J23.20, J24.3, J25.2, U5.14, U5.15, U5.16, U5.17, U5.18, U5.19, U5.20
GND5: B6.1, B6.4, B6.21, B6.37, B6.40, C26.2, C27.2, C28.2, C29.2, C30.2, D6.C, J26.GND, J26.GND1, J26.GND3, J27.1, J27.4, J28.1, J28.17, J28.20, J29.3, J30.2, U6.14, U6.15, U6.16, U6.17, U6.18, U6.19, U6.20
GND6: B7.1, B7.4, B7.21, B7.37, B7.40, C31.2, C32.2, C33.2, C34.2, C35.2, D7.C, J31.GND, J31.GND1, J31.GND3, J32.1, J32.4, J33.1, J33.17, J33.20, J34.3, J35.2, U7.14, U7.15, U7.16, U7.17, U7.18, U7.19, U7.20
GND7: B8.1, B8.4, B8.21, B8.37, B8.40, C36.2, C37.2, C38.2, C39.2, C40.2, D8.C, J36.GND, J36.GND1, J36.GND3, J37.1, J37.4, J38.1, J38.17, J38.20, J39.3, J40.2, U8.14, U8.15, U8.16, U8.17, U8.18, U8.19, U8.20
GND8: B9.1, B9.4, B9.21, B9.37, B9.40, C41.2, C42.2, C43.2, C44.2, C45.2, D9.C, J41.GND, J41.GND1, J41.GND3, J42.1, J42.4, J43.1, J43.17, J43.20, J44.3, J45.2, U9.14, U9.15, U9.16, U9.17, U9.18, U9.19, U9.20
GND9: B10.1, B10.4, B10.21, B10.37, B10.40, C46.2, C47.2, C48.2, C49.2, C50.2, D10.C, J46.GND, J46.GND1, J46.GND3, J47.1, J47.4, J48.1, J48.17, J48.20, J49.3, J50.2, U10.14, U10.15, U10.16, U10.17, U10.18, U10.19, U10.20
GND10: B11.1, B11.4, B11.21, B11.37, B11.40, C51.2, C52.2, C53.2, C54.2, C55.2, D11.C, J51.GND, J51.GND1, J51.GND3, J52.1, J52.4, J53.1, J53.17, J53.20, J54.3, J55.2, U11.14, U11.15, U11.16, U11.17, U11.18, U11.19, U11.20
GND11: B12.1, B12.4, B12.21, B12.37, B12.40, C56.2, C57.2, C58.2, C59.2, C60.2, D12.C, J56.GND, J56.GND1, J56.GND3, J57.1, J57.4, J58.1, J58.17, J58.20, J59.3, J60.2, U12.14, U12.15, U12.16, U12.17, U12.18, U12.19, U12.20
GND12: B13.1, B13.4, B13.21, B13.37, B13.40, C61.2, C62.2, C63.2, C64.2, C65.2, D13.C, J61.GND, J61.GND1, J61.GND3, J62.1, J62.4, J63.1, J63.17, J63.20, J64.3, J65.2, U13.14, U13.15, U13.16, U13.17, U13.18, U13.19, U13.20
GND13: B14.1, B14.4, B14.21, B14.37, B14.40, C66.2, C67.2, C68.2, C69.2, C70.2, D14.C, J66.GND, J66.GND1, J66.GND3, J67.1, J67.4, J68.1, J68.17, J68.20, J69.3, J70.2, U14.14, U14.15, U14.16, U14.17, U14.18, U14.19, U14.20
GND14: B15.1, B15.4, B15.21, B15.37, B15.40, C71.2, C72.2, C73.2, C74.2, C75.2, D15.C, J71.GND, J71.GND1, J71.GND3, J72.1, J72.4, J73.1, J73.17, J73.20, J74.3, J75.2, U15.14, U15.15, U15.16, U15.17, U15.18, U15.19, U15.20
GND15: B16.1, B16.4, B16.21, B16.37, B16.40, C76.2, C77.2, C78.2, C79.2, C80.2, D16.C, J76.GND, J76.GND1, J76.GND3, J77.1, J77.4, J78.1, J78.17, J78.20, J79.3, J80.2, U16.14, U16.15, U16.16, U16.17, U16.18, U16.19, U16.20
GND16: B17.1, B17.4, B17.21, B17.37, B17.40, C81.2, C82.2, C83.2, C84.2, C85.2, D17.C, J81.GND, J81.GND1, J81.GND3, J82.1, J82.4, J83.1, J83.17, J83.20, J84.3, J85.2, U17.14, U17.15, U17.16, U17.17, U17.18, U17.19, U17.20
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

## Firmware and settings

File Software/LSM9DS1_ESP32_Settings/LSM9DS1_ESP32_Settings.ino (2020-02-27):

/*****************************************************************
LSM9DS1_ESP32_Settings.ino
SFE_LSM9DS1 Library Settings Configuration Example
Original Creation: August 13, 2015 by Jim Lindblom
https://github.com/sparkfun/LSM9DS1_Breakout

This Arduino sketch demonstrates how to configure every 
possible configuration value in the SparkFunLSM9DS1 library.

It demonstrates how to set the output data rates and scales
for each sensor, along with other settings like LPF cutoff
frequencies and low-power settings.

It also demonstrates how to turn various sensors in the
LSM9DS1 on or off.

Hardware setup: This library is intended to be used with a 
ESP32 Motion shield connected directly to the ESP32 Thing.

Development environment specifics:
  IDE: Arduino 1.8.2
  Hardware Platform: ESP32 Arduion Board

This code is beerware. If you see me (or any other SparkFun 
employee) at the local, and you've found our code helpful, 
please buy us a round!

Distributed as-is; no warranty is given.
*****************************************************************/
// Include SparkFunLSM9DS1 library and its dependencies
#include <Wire.h>
#include <SPI.h>
#include <SparkFunLSM9DS1.h>

LSM9DS1 imu;  // Create an LSM9DS1 object

// Mag address must be 0x1E, would be 0x1C if SDO_M is LOW
#define LSM9DS1_M	0x1E
// Accel/gyro address must be 0x6B, would be 0x6A if SDO_AG is LOW
#define LSM9DS1_AG	0x6B

// Global variables to keep track of update rates
unsigned long startTime;
unsigned int accelReadCounter = 0;
unsigned int gyroReadCounter = 0;
unsigned int magReadCounter = 0;
unsigned int tempReadCounter = 0;

// Global variables to print to serial monitor at a steady rate
unsigned long lastPrint = 0;
const unsigned int PRINT_RATE = 500;

void setupGyro()
{
  // [enabled] turns the gyro on or off.
  imu.settings.gyro.enabled = true;  // Enable the gyro
  // [scale] sets the full-scale range of the gyroscope.
  // scale can be set to either 245, 500, or 2000
  imu.settings.gyro.scale = 245; // Set scale to +/-245dps
  // [sampleRate] sets the output data rate (ODR) of the gyro
  // sampleRate can be set between 1-6
  // 1 = 14.9    4 = 238
  // 2 = 59.5    5 = 476
  // 3 = 119     6 = 952
  imu.settings.gyro.sampleRate = 3; // 59.5Hz ODR
  // [bandwidth] can set the cutoff frequency of the gyro.
  // Allowed values: 0-3. Actual value of cutoff frequency
  // depends on the sample rate. (Datasheet section 7.12)
  imu.settings.gyro.bandwidth = 0;
  // [lowPowerEnable] turns low-power mode on or off.
  imu.settings.gyro.lowPowerEnable = false; // LP mode off
  // [HPFEnable] enables or disables the high-pass filter
  imu.settings.gyro.HPFEnable = true; // HPF disabled
  // [HPFCutoff] sets the HPF cutoff frequency (if enabled)
  // Allowable values are 0-9. Value depends on ODR.
  // (Datasheet section 7.14)
  imu.settings.gyro.HPFCutoff = 1; // HPF cutoff = 4Hz
  // [flipX], [flipY], and [flipZ] are booleans that can
  // automatically switch the positive/negative orientation
  // of the three gyro axes.
  imu.settings.gyro.flipX = false; // Don't flip X
  imu.settings.gyro.flipY = false; // Don't flip Y
  imu.settings.gyro.flipZ = false; // Don't flip Z
}

void setupAccel()
{
  // [enabled] turns the acclerometer on or off.
  imu.settings.accel.enabled = true; // Enable accelerometer
  // [enableX], [enableY], and [enableZ] can turn on or off
  // select axes of the acclerometer.
  imu.settings.accel.enableX = true; // Enable X
  imu.settings.accel.enableY = true; // Enable Y
  imu.settings.accel.enableZ = true; // Enable Z
  // [scale] sets the full-scale range of the accelerometer.
  // accel scale can be 2, 4, 8, or 16
  imu.settings.accel.scale = 8; // Set accel scale to +/-8g.
  // [sampleRate] sets the output data rate (ODR) of the
  // accelerometer. ONLY APPLICABLE WHEN THE GYROSCOPE IS
  // DISABLED! Otherwise accel sample rate = gyro sample rate.
  // accel sample rate can be 1-6
  // 1 = 10 Hz    4 = 238 Hz
  // 2 = 50 Hz    5 = 476 Hz
  // 3 = 119 Hz   6 = 952 Hz
  imu.settings.accel.sampleRate = 1; // Set accel to 10Hz.
  // [bandwidth] sets the anti-aliasing filter bandwidth.
  // Accel cutoff freqeuncy can be any value between -1 - 3. 
  // -1 = bandwidth determined by sample rate
  // 0 = 408 Hz   2 = 105 Hz
  // 1 = 211 Hz   3 = 50 Hz
  imu.settings.accel.bandwidth = 0; // BW = 408Hz
  // [highResEnable] enables or disables high resolution 
  // mode for the acclerometer.
  imu.settings.accel.highResEnable = false; // Disable HR
  // [highResBandwidth] sets the LP cutoff frequency of
  // the accelerometer if it's in high-res mode.
  // can be any value between 0-3
  // LP cutoff is set to a factor of sample rate
  // 0 = ODR/50    2 = ODR/9
  // 1 = ODR/100   3 = ODR/400
  imu.settings.accel.highResBandwidth = 0;  
}

void setupMag()
{
  // [enabled] turns the magnetometer on or off.
  imu.settings.mag.enabled = true; // Enable magnetometer
  // [scale] sets the full-scale range of the magnetometer
  // mag scale can be 4, 8, 12, or 16
  imu.settings.mag.scale = 12; // Set mag scale to +/-12 Gs
  // [sampleRate] sets the output data rate (ODR) of the
  // magnetometer.
  // mag data rate can be 0-7:
  // 0 = 0.625 Hz  4 = 10 Hz
  // 1 = 1.25 Hz   5 = 20 Hz
  // 2 = 2.5 Hz    6 = 40 Hz
  // 3 = 5 Hz      7 = 80 Hz
  imu.settings.mag.sampleRate = 5; // Set OD rate to 20Hz
  // [tempCompensationEnable] enables or disables 
  // temperature compensation of the magnetometer.
  imu.settings.mag.tempCompensationEnable = false;
  // [XYPerformance] sets the x and y-axis performance of the
  // magnetometer to either:
  // 0 = Low power mode      2 = high performance
  // 1 = medium performance  3 = ultra-high performance
  imu.settings.mag.XYPerformance = 3; // Ultra-high perform.
  // [ZPerformance] does the same thing, but only for the z
  imu.settings.mag.ZPerformance = 3; // Ultra-high perform.
  // [lowPowerEnable] enables or disables low power mode in
  // the magnetometer.
  imu.settings.mag.lowPowerEnable = false;
  // [operatingMode] sets the operating mode of the
  // magnetometer. operatingMode can be 0-2:
  // 0 = continuous conversion
  // 1 = single-conversion
  // 2 = power down
  imu.settings.mag.operatingMode = 0; // Continuous mode
}

void setupTemperature()
{
  // [enabled] turns the temperature sensor on or off.
  imu.settings.temp.enabled = true;
}

uint16_t initLSM9DS1()
{
  setupGyro(); // Set up gyroscope parameters
  setupAccel(); // Set up accelerometer parameters
  setupMag(); // Set up magnetometer parameters
  setupTemperature(); // Set up temp sensor parameter
  
  return imu.begin(LSM9DS1_AG, LSM9DS1_M, Wire); 
}

void setup() 
{
  Serial.begin(115200);

  Wire.begin();
  
  Serial.println("Initializing the LSM9DS1");
  uint16_t status = initLSM9DS1();
  Serial.print("LSM9DS1 WHO_AM_I's returned: 0x");
  Serial.println(status, HEX);
  Serial.println("Should be 0x683D");
  Serial.println();
  
  startTime = millis();
}

void loop() 
{  
  // imu.accelAvailable() returns 1 if new accelerometer
  // data is ready to be read. 0 otherwise.
  if (imu.accelAvailable())
  {
    imu.readAccel();
    accelReadCounter++;
  }
  
  // imu.gyroAvailable() returns 1 if new gyroscope
  // data is ready to be read. 0 otherwise.
  if (imu.gyroAvailable())
  {
    imu.readGyro();
    gyroReadCounter++;
  }
  
  // imu.magAvailable() returns 1 if new magnetometer
  // data is ready to be read. 0 otherwise.
  if (imu.magAvailable())
  {
    imu.readMag();
    magReadCounter++;
  }
  
  // imu.tempAvailable() returns 1 if new temperature sensor
  // data is ready to be read. 0 otherwise.
  if (imu.tempAvailable())
  {
    imu.readTemp();
    tempReadCounter++;
  }

  // Every PRINT_RATE milliseconds, print sensor data:
  if ((lastPrint + PRINT_RATE) < millis())
  {
    printSensorReadings();
    lastPrint = millis();
  }
}

// printSensorReadings prints the latest IMU readings
// along with a calculated update rate.
void printSensorReadings()
{
  float runTime = (float)(millis() - startTime) / 1000.0;
  float accelRate = (float)accelReadCounter / runTime;
  float gyroRate = (float)gyroReadCounter / runTime;
  float magRate = (float)magReadCounter / runTime;
  float tempRate = (float)tempReadCounter / runTime;
  Serial.print("A: ");
  Serial.print(imu.calcAccel(imu.ax));
  Serial.print(", ");
  Serial.print(imu.calcAccel(imu.ay));
  Serial.print(", ");
  Serial.print(imu.calcAccel(imu.az));
  Serial.print(" g \t| ");
  Serial.print(accelRate);
  Serial.println(" Hz");
  Serial.print("G: ");
  Serial.print(imu.calcGyro(imu.gx));
  Serial.print(", ");
  Serial.print(imu.calcGyro(imu.gy));
  Serial.print(", ");
  Serial.print(imu.calcGyro(imu.gz));
  Serial.print(" dps \t| ");
  Serial.print(gyroRate);
  Serial.println(" Hz");
  Serial.print("M: ");
  Serial.print(imu.calcMag(imu.mx));
  Serial.print(", ");
  Serial.print(imu.calcMag(imu.my));
  Serial.print(", ");
  Serial.print(imu.calcMag(imu.mz));
  Serial.print(" Gs \t| ");
  Serial.print(magRate);
  Serial.println(" Hz");
  Serial.print("T: ");
  Serial.print(imu.temperature);
  Serial.print(" \t\t\t| ");
  Serial.print(tempRate);
  Serial.println(" Hz");  
  Serial.println();
}

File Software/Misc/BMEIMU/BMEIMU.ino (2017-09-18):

/******************************************************************************
CSV_Output.ino
BME280 Arduino and Teensy example
Marshall Taylor @ SparkFun Electronics
May 20, 2015
https://github.com/sparkfun/SparkFun_BME280_Arduino_Library

This sketch configures two BME280 to produce comma separated values for use
in generating spreadsheet graphs.
in 10 being used for chip select.

Resources:
Uses Wire.h for I2C operation
Uses SPI.h for SPI operation

Development environment specifics:
Arduino IDE 1.6.4
Teensy loader 1.23

This code is released under the [MIT License](http://opensource.org/licenses/MIT).
Please review the LICENSE.md file included with this example. If you have any questions 
or concerns with licensing, please contact techsupport@sparkfun.com.
Distributed as-is; no warranty is given.
******************************************************************************/

#include <stdint.h>
#include "SparkFunBME280.h"

#include "Wire.h"
#include "SPI.h"

#include <SparkFunLSM9DS1.h>

LSM9DS1 imu;
#define LSM9DS1_M	0x1E // Would be 0x1C if SDO_M is LOW
#define LSM9DS1_AG	0x6B // Would be 0x6A if SDO_AG is LOW
#define LSM9DS1_VDD_CTRL 27
#define LSM9DS1_VDDIO_CTRL 34
#define PRINT_SPEED 250 // 250 ms between prints
static unsigned long lastPrint = 0; // Keep track of print time
#define DECLINATION -8.58 // Declination (degrees) in Boulder, CO.

//Internal variables
float roll;
float pitch;
float heading;
char csvBuffer[300];

//Global sensor object
BME280 mySensor;

unsigned int sampleNumber = 0; //For counting number of CSV rows

void setup()
{
	Serial.begin(115200);

	pinMode( LSM9DS1_VDDIO_CTRL, OUTPUT );
  digitalWrite( LSM9DS1_VDDIO_CTRL, 1 );
  
  pinMode( LSM9DS1_VDD_CTRL, OUTPUT );
  digitalWrite( LSM9DS1_VDD_CTRL, 1 );
  delay(100);
  digitalWrite( LSM9DS1_VDDIO_CTRL, 0 );
  digitalWrite( LSM9DS1_VDD_CTRL, 0 );
  
  delay(1000);
  Serial.println("Starting Sketch");

  //***Driver settings********************************//
	//commInterface can be I2C_MODE or SPI_MODE
	//specify chipSelectPin using arduino pin names
	//specify I2C address.  Can be 0x77(default) or 0x76
	
	//For I2C, enable the following and disable the SPI section
	mySensor.settings.commInterface = I2C_MODE;
	mySensor.settings.I2CAddress = 0x77;
	//***Operation settings*****************************//
	mySensor.settings.runMode = 3; //  3, Normal mode
	mySensor.settings.tStandby = 0; //  0, 0.5ms
	mySensor.settings.filter = 0; //  0, filter off
	mySensor.settings.tempOverSample = 1;
    mySensor.settings.pressOverSample = 1;
	mySensor.settings.humidOverSample = 1;
	
  imu.settings.device.commInterface = IMU_MODE_I2C;
  imu.settings.device.mAddress = LSM9DS1_M;
  imu.settings.device.agAddress = LSM9DS1_AG;
  // The above lines will only take effect AFTER calling
  // imu.begin(), which verifies communication with the IMU
  // and turns it on.
  imu.settings.mag.scale = 2;
  

	Serial.print("Starting BME280... result of .begin(): 0x");
	delay(10);  //Make sure sensor had enough time to turn on. BME280 requires 2ms to start up.
	//Calling .begin() causes the settings to be loaded
	Serial.println(mySensor.begin(), HEX);

	delay(100);
  if (!imu.begin())
  {
    Serial.println("Failed to communicate with LSM9DS1.");
    Serial.println("Double-check wiring.");
    Serial.println("Default settings in this sketch will " \
                  "work for an out of the box LSM9DS1 " \
                  "Breakout, but may need to be modified " \
                  "if the board jumpers are.");
    while (1)
      ;
  }
	


}

void loop()
{
  if ( imu.gyroAvailable() )
  {
    // To read from the gyroscope,  first call the
    // readGyro() function. When it exits, it'll update the
    // gx, gy, and gz variables with the most current data.
    imu.readGyro();
  }
  if ( imu.accelAvailable() )
  {
    // To read from the accelerometer, first call the
    // readAccel() function. When it exits, it'll update the
    // ax, ay, and az variables with the most current data.
    imu.readAccel();
  }
  if ( imu.magAvailable() )
  {
    // To read from the magnetometer, first call the
    // readMag() function. When it exits, it'll update the
    // mx, my, and mz variables with the most current data.
    imu.readMag();
  }
  if ((lastPrint + PRINT_SPEED) < millis())
  {
	//Print each row in the loop
	//Start with temperature, as that data is needed for accurate compensation.
	//Reading the temperature updates the compensators of the other functions
	//in the background.
	Serial.print(sampleNumber);
	Serial.print(",");
	Serial.print(mySensor.readTempC(), 2);
	Serial.print(",");
	Serial.print(mySensor.readTempF(), 3);
	Serial.print(",");
	Serial.print(mySensor.readFloatPressure(), 0);
	Serial.print(",");
	Serial.print(mySensor.readFloatAltitudeMeters(), 3);
	Serial.print(",");
	Serial.print(mySensor.readFloatAltitudeFeet(), 3);
	Serial.print(",");
	Serial.print(mySensor.readFloatHumidity(), 0);
	Serial.println();
	
	sampleNumber++;

    calcAttitude(imu.ax, imu.ay, imu.az, -imu.my, -imu.mx, imu.mz);
	float data1 = imu.calcGyro(imu.gx);
	float data2 = imu.calcGyro(imu.gy);
	float data3 = imu.calcGyro(imu.gz);
	float data4 = imu.calcAccel(imu.ax);
	float data5 = imu.calcAccel(imu.ay);
	float data6 = imu.calcAccel(imu.az);
	float data7 = imu.calcMag(imu.mx);
	float data8 = imu.calcMag(imu.my);
	float data9 = imu.calcMag(imu.mz);

	sprintf(csvBuffer, "%4.3f,%4.3f,%4.3f,%4.3f,%4.3f,%4.3f,%4.3f,%4.3f,%4.3f,%4.3f,%4.3f,%4.3f,", data1, data2, data3, data4, data5, data6, data7, data8, data9, roll, pitch, heading);
	//sprintf(csvBuffer, "%4.3f", heading);
	Serial.print(csvBuffer);
    Serial.println();
	
    Serial.println();
    
    lastPrint = millis(); // Update lastPrint time
	
  }

}

void printGyro()
{
  Serial.print("G: ");
  Serial.print(imu.calcGyro(imu.gx), 2);
  Serial.print(", ");
  Serial.print(imu.calcGyro(imu.gy), 2);
  Serial.print(", ");
  Serial.print(imu.calcGyro(imu.gz), 2);
  Serial.println(" deg/s");

}

void printAccel()
{  
  Serial.print("A: ");
  Serial.print(imu.calcAccel(imu.ax), 2);
  Serial.print(", ");
  Serial.print(imu.calcAccel(imu.ay), 2);
  Serial.print(", ");
  Serial.print(imu.calcAccel(imu.az), 2);
  Serial.println(" g");

}

void printMag()
{  
  Serial.print("M: ");
  Serial.print(imu.calcMag(imu.mx), 2);
  Serial.print(", ");
  Serial.print(imu.calcMag(imu.my), 2);
  Serial.print(", ");
  Serial.print(imu.calcMag(imu.mz), 2);
  Serial.println(" gauss");
}
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

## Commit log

2017-08-04 Preliminary design complete
    [ESP32_GPS_Motion_Shield.brd, ESP32_GPS_Motion_Shield.sch]
2017-08-07 Checked DRC, ready for kickoff
    [ESP32_GPS_Motion_Shield.brd]
2017-08-07 Switched to other GPS jack
    [ESP32_GPS_Motion_Shield.brd, ESP32_GPS_Motion_Shield.sch]
2017-08-08 Ready for review
    [ESP32_GPS_Motion_Shield.brd, ESP32_GPS_Motion_Shield.sch]
2017-08-08 Ready for QC review
    [ESP32_GPS_Motion_Shield.brd, ESP32_GPS_Motion_Shield.sch]
2017-08-08 Fixed v01 check issues
    [ESP32_GPS_Motion_Shield.brd]
2017-09-18 Reviewing for reds
    [ESP32_GPS_Motion_Shield.brd, ESP32_GPS_Motion_Shield.sch]
2017-09-19 Double checked layout vs. fixed proto. Adjusted small shapes.
    [ESP32_GPS_Motion_Shield.brd, ESP32_GPS_Motion_Shield.sch]
2017-09-22 Fixed items from redboard review
    [ESP32_GPS_Motion_Shield.brd, ESP32_GPS_Motion_Shield.sch]
2017-11-01 Removed v01 design
    [ESP32_GPS_Motion_Shield.brd, ESP32_GPS_Motion_Shield.sch]
2020-02-27 Update Software Folder for Library Updates
    Updated examples to add compatibility with latest versions of LSM9DS1 and BME280 libraries along with ESP32 Arduino Core.
    Add calls to Wire.begin(); and updated sensor init functions to latest versions of libraries.
    Fixed Serial1 calls to work with latest version of ESP32 Arduino Core.
    Removed MISC examples as they are outdated.
    [BME280_I2C_SPI.ino, BMEIMU.ino, GPS_IMU_SD_Logger.ino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]

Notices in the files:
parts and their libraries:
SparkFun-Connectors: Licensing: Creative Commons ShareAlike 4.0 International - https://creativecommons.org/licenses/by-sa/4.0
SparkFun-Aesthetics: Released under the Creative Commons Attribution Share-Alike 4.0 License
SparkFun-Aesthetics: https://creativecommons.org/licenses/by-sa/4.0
